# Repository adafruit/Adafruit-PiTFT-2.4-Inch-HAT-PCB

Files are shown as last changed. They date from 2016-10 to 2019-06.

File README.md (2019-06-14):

## Adafruit PiTFT 2.4 Inch HAT PCB

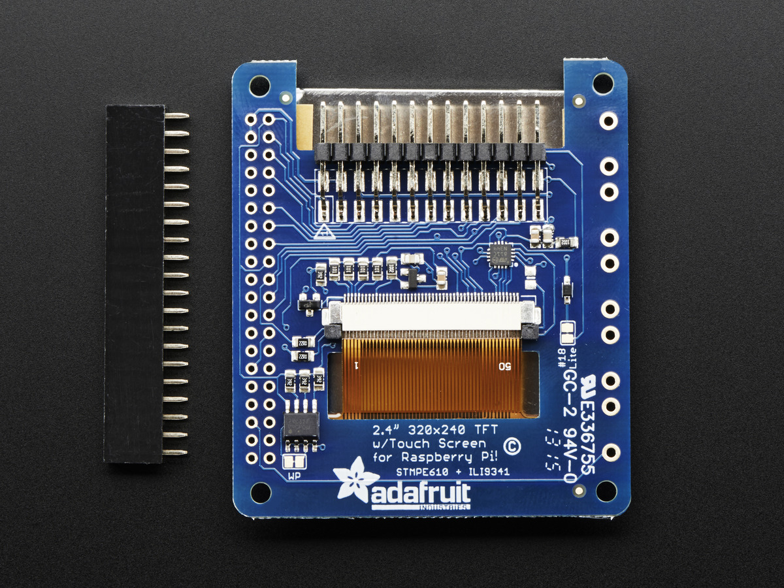
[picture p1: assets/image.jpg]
<a href="http://www.adafruit.com/products/2455"><br/>
Click here to purchase one from the Adafruit shop</a>

PCB files for the Adafruit PiTFT 2.4 Inch HAT. Format is EagleCAD schematic and board layout
* https://www.adafruit.com/product/2455

### DESCRIPTION
Is this not the cutest little display for the Raspberry Pi? It features a 2.4" display with 320x240 16-bit color pixels and a resistive touch overlay. The HAT uses the high speed SPI interface on the Pi and can use the mini display as a console, X window port, displaying images or video etc. Best of all it plugs right in on top!

It's designed to fit nicely onto the Pi Model Zero, A+, B+, Pi 2, Pi 3 - any Pi with a 2x20 connector.

This design uses the hardware SPI pins (SCK, MOSI, MISO, CE0, CE1) as well as GPIO #25 and #24. All other GPIO are unused. Since we had a tiny bit of space, there's 5 spots for optional slim tactile switches wired to five GPIOs, that you can use if you want to make a basic user interface. For example, you can use one as a power on/off button.

We have a right-angle 26-pin connector off to the side. You can connect a classic 26-pin Raspberry Pi GPIO cable in order to access the rest of the GPIO through a Cobbler, etc.

To make it super easy for use: we've created a custom kernel package based of off Notro's awesome framebuffer work, so you can install it over your existing Raspbian (or derivative) images in just a few commands.

Each order ships with an assembled HAT with 2.4" TFT display with resistive touchscreen and a 2x20 female socket header. Some light soldering is required to attach the header but it is easy work for anyone with a soldering iron & solder.Alternatively, you can use a stacking type header instead if you'd like to plug a 2x20 GPIO cable on top

Raspberry Pi, Pi enclosure, 26-pin GPIO cable, tactile switches are not included!

### License

Adafruit invests time and resources providing this open source design, please support Adafruit and open-source hardware by purchasing products from [Adafruit.com](https://www.adafruit.com)!

Creative Commons Attribution, Share-Alike license, check license.txt for more information All text above must be included in any redistribution - 
See license.txt for more information.

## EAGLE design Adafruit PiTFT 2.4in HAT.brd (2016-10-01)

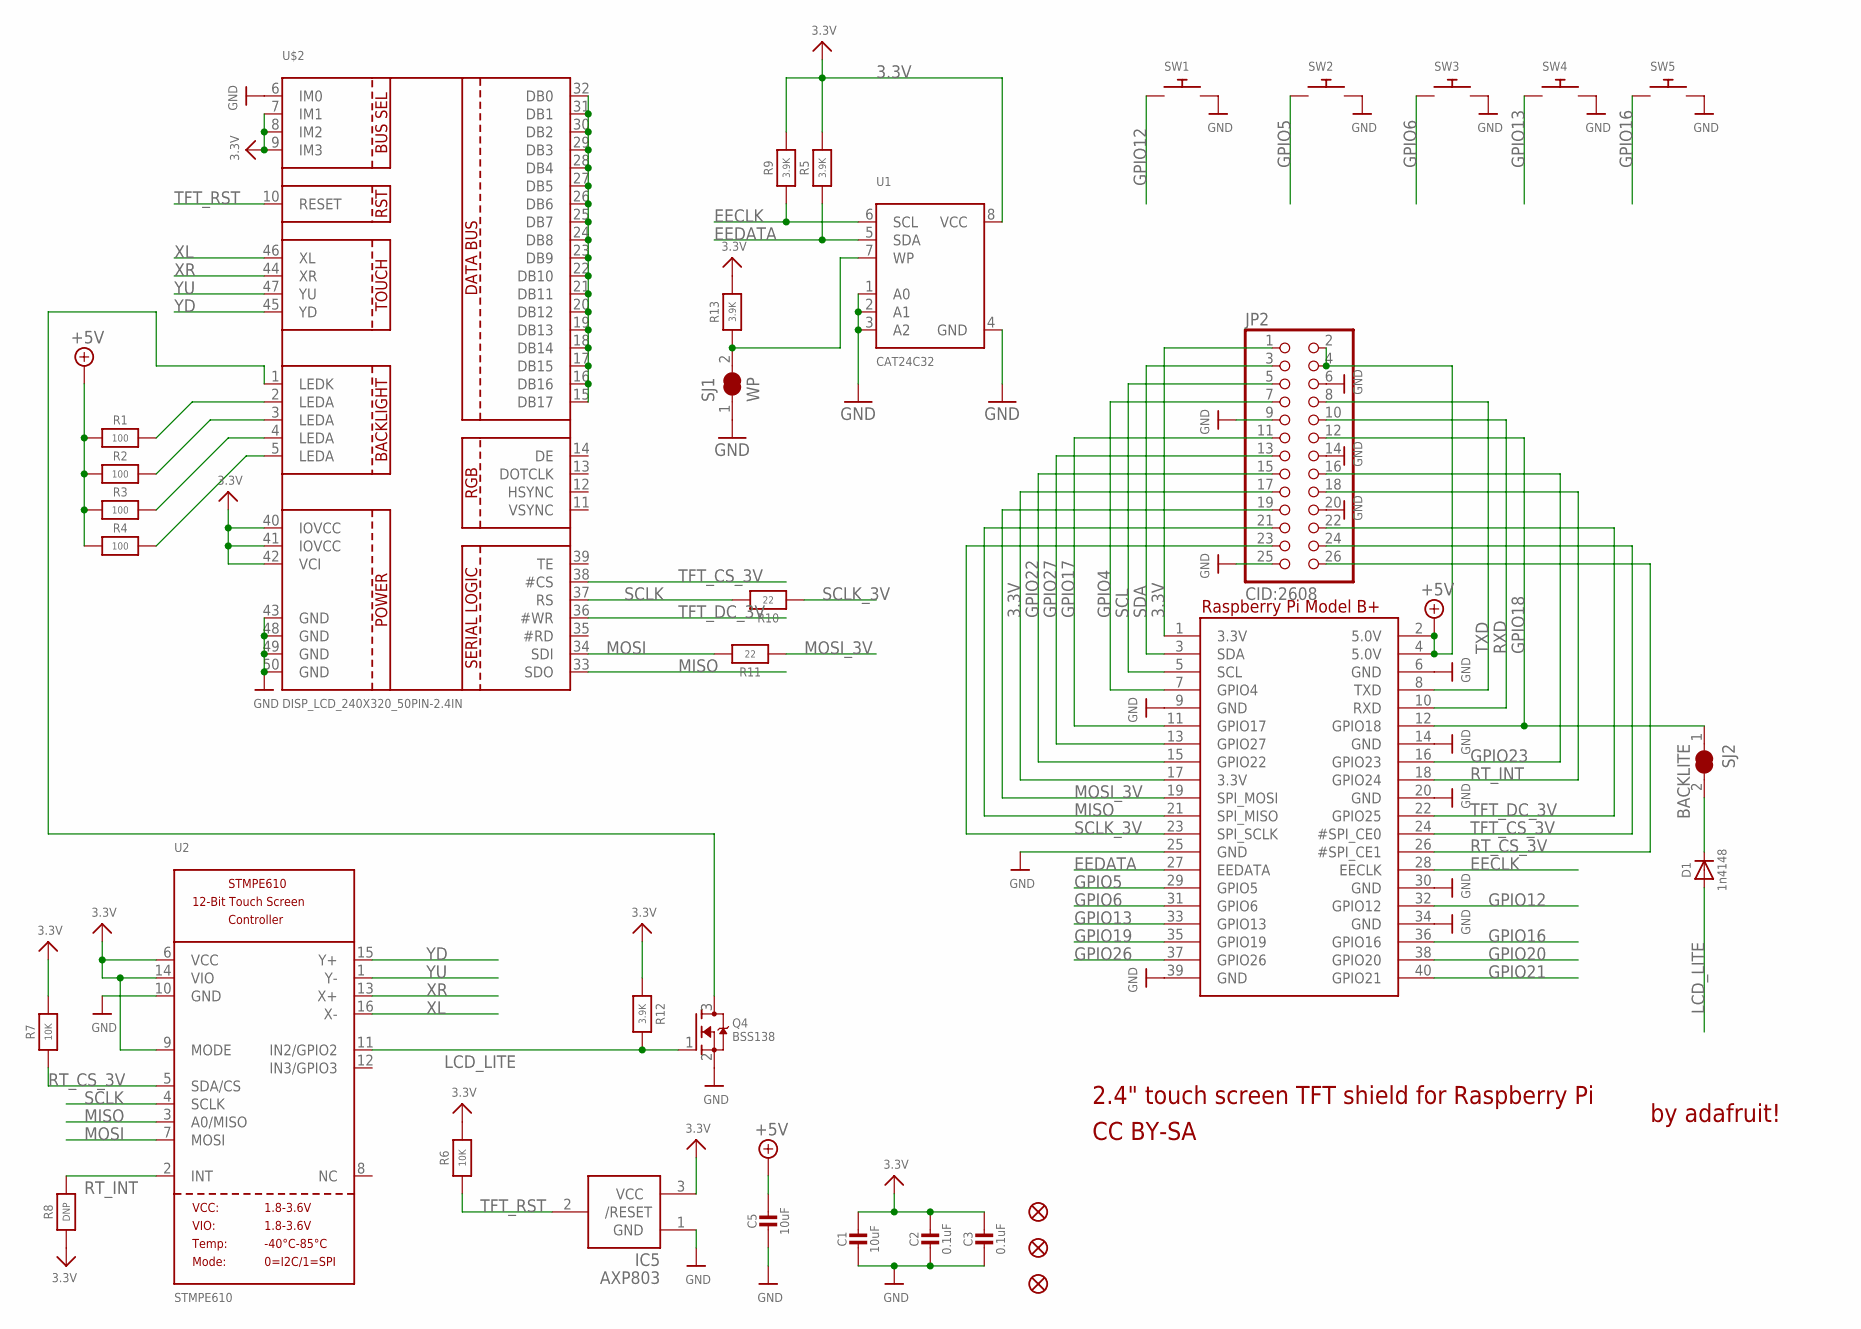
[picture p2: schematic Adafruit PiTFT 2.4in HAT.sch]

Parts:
C1, C5: 10uF; 0805-NO
C2, C3: 0.1uF; 0805-NO
D1: 1n4148; SOD-323
IC5: AXP803; SOT23
JP2: CID:2608; 2X13_SMT_MALE
Q4: BSS138; SOT23-WIDE
R1, R2, R3, R4: 100; 0805-NO
R5, R9, R12, R13: 3.9K; 0805-NO
R6, R7: 10K; 0805-NO
R8: DNP; 0805-NO
R10, R11: 22; 0805-NO
RPI1: RASPBERRYPI_BPLUS_HATNOSLOTS; PI_HAT_NOSLOTS
SJ1: WP; SOLDERJUMPER_CLOSEDWIRE
SJ2: BACKLITE; SOLDERJUMPER_CLOSEDWIRE
SW1, SW2, SW3, SW4, SW5: SWITCH_PUSHBUTTONEVQ-PE; TACT_PANA-EVQ
U1: CAT24C32; SOIC8_150MIL
U2: STMPE610; QFN16_3MM
U$2: DISP_LCD_240X320_50PIN-2.4IN; TFT_2.4IN_240X320_50PIN
U$10, U$11, U$18: FIDUCIAL""; FIDUCIAL_1MM

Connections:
3.3V: C1.1, C2.1, C3.1, IC5.3 (VCC), JP2.1, JP2.17, R5.2, R6.2, R7.2, R8.1, R9.2, R12.1, R13.2, RPI1.1 (3.3V), RPI1.17 (3.3V), U1.8 (VCC), U2.6 (VCC), U2.9 (MODE), U2.14 (VIO), U$2.7 (IM1), U$2.8 (IM2), U$2.9 (IM3), U$2.40 (IOVCC), U$2.41 (IOVCC), U$2.42 (VCI)
+5V: C5.1, JP2.2, JP2.4, R1.1, R2.1, R3.1, R4.1, RPI1.2 (5.0V), RPI1.4 (5.0V)
EECLK: R9.1, RPI1.28 (EECLK), U1.6 (SCL)
EEDATA: R5.1, RPI1.27 (EEDATA), U1.5 (SDA)
GND: C1.2, C2.2, C3.2, C5.2, IC5.1 (GND), JP2.6, JP2.9, JP2.14, JP2.20, JP2.25, Q4.2 (S), RPI1.6 (GND), RPI1.9 (GND), RPI1.14 (GND), RPI1.20 (GND), RPI1.25 (GND), RPI1.30 (GND), RPI1.34 (GND), RPI1.39 (GND), SJ1.1, SW1.P$2, SW2.P$2, SW3.P$2, SW4.P$2, SW5.P$2, U1.1 (A0), U1.2 (A1), U1.3 (A2), U1.4 (GND), U2.10 (GND), U$2.6 (IM0), U$2.43 (GND), U$2.48 (GND), U$2.49 (GND), U$2.50 (GND)
GPIO4: JP2.7, RPI1.7 (GPIO4)
GPIO5: RPI1.29 (GPIO5), SW2.P$1
GPIO6: RPI1.31 (GPIO6), SW3.P$1
GPIO12: RPI1.32 (GPIO12), SW1.P$1
GPIO13: RPI1.33 (GPIO13), SW4.P$1
GPIO16: RPI1.36 (GPIO16), SW5.P$1
GPIO17: JP2.11, RPI1.11 (GPIO17)
GPIO18: JP2.12, RPI1.12 (GPIO18), SJ2.1
GPIO19: RPI1.35 (GPIO19)
GPIO20: RPI1.38 (GPIO20)
GPIO21: RPI1.40 (GPIO21)
GPIO22: JP2.15, RPI1.15 (GPIO22)
GPIO23: JP2.16, RPI1.16 (GPIO23)
GPIO26: RPI1.37 (GPIO26)
GPIO27: JP2.13, RPI1.13 (GPIO27)
LCD_LITE: D1.A, Q4.1 (G), R12.2, U2.11 (IN2/GPIO2)
MISO: JP2.21, RPI1.21 (SPI_MISO), U2.3 (A0/MISO), U$2.33 (SDO)
MOSI: R11.2, U2.7 (MOSI), U$2.34 (SDI)
MOSI_3V: JP2.19, R11.1, RPI1.19 (SPI_MOSI)
unnamed: R1.2, U$2.2 (LEDA)
unnamed: R2.2, U$2.3 (LEDA)
unnamed: R3.2, U$2.4 (LEDA)
unnamed: Q4.3 (D), U$2.1 (LEDK)
unnamed: D1.C, SJ2.2
unnamed: U$2.15 (DB17), U$2.16 (DB16), U$2.17 (DB15), U$2.18 (DB14), U$2.19 (DB13), U$2.20 (DB12), U$2.21 (DB11), U$2.22 (DB10), U$2.23 (DB9), U$2.24 (DB8), U$2.25 (DB7), U$2.26 (DB6), U$2.27 (DB5), U$2.28 (DB4), U$2.29 (DB3), U$2.30 (DB2), U$2.31 (DB1), U$2.32 (DB0)
unnamed: R4.2, U$2.5 (LEDA)
unnamed: R13.1, SJ1.2, U1.7 (WP)
RT_CS_3V: JP2.26, R7.1, RPI1.26 (#SPI_CE1), U2.5 (SDA/CS)
RT_INT: JP2.18, R8.2, RPI1.18 (GPIO24), U2.2 (INT)
RXD: JP2.10, RPI1.10 (RXD)
SCL: JP2.5, RPI1.5 (SCL)
SCLK: R10.2, U2.4 (SCLK), U$2.37 (RS)
SCLK_3V: JP2.23, R10.1, RPI1.23 (SPI_SCLK)
SDA: JP2.3, RPI1.3 (SDA)
TFT_CS_3V: JP2.24, RPI1.24 (#SPI_CE0), U$2.38 (#CS)
TFT_DC_3V: JP2.22, RPI1.22 (GPIO25), U$2.36 (#WR)
TFT_RST: IC5.2 (/RESET), R6.1, U$2.10 (RESET)
TXD: JP2.8, RPI1.8 (TXD)
XL: U2.16 (X-), U$2.46 (XL)
XR: U2.13 (X+), U$2.44 (XR)
YD: U2.15 (Y+), U$2.45 (YD)
YU: U2.1 (Y-), U$2.47 (YU)

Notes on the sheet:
2.4" touch screen TFT shield for Raspberry Pi
by adafruit!
CC BY-SA

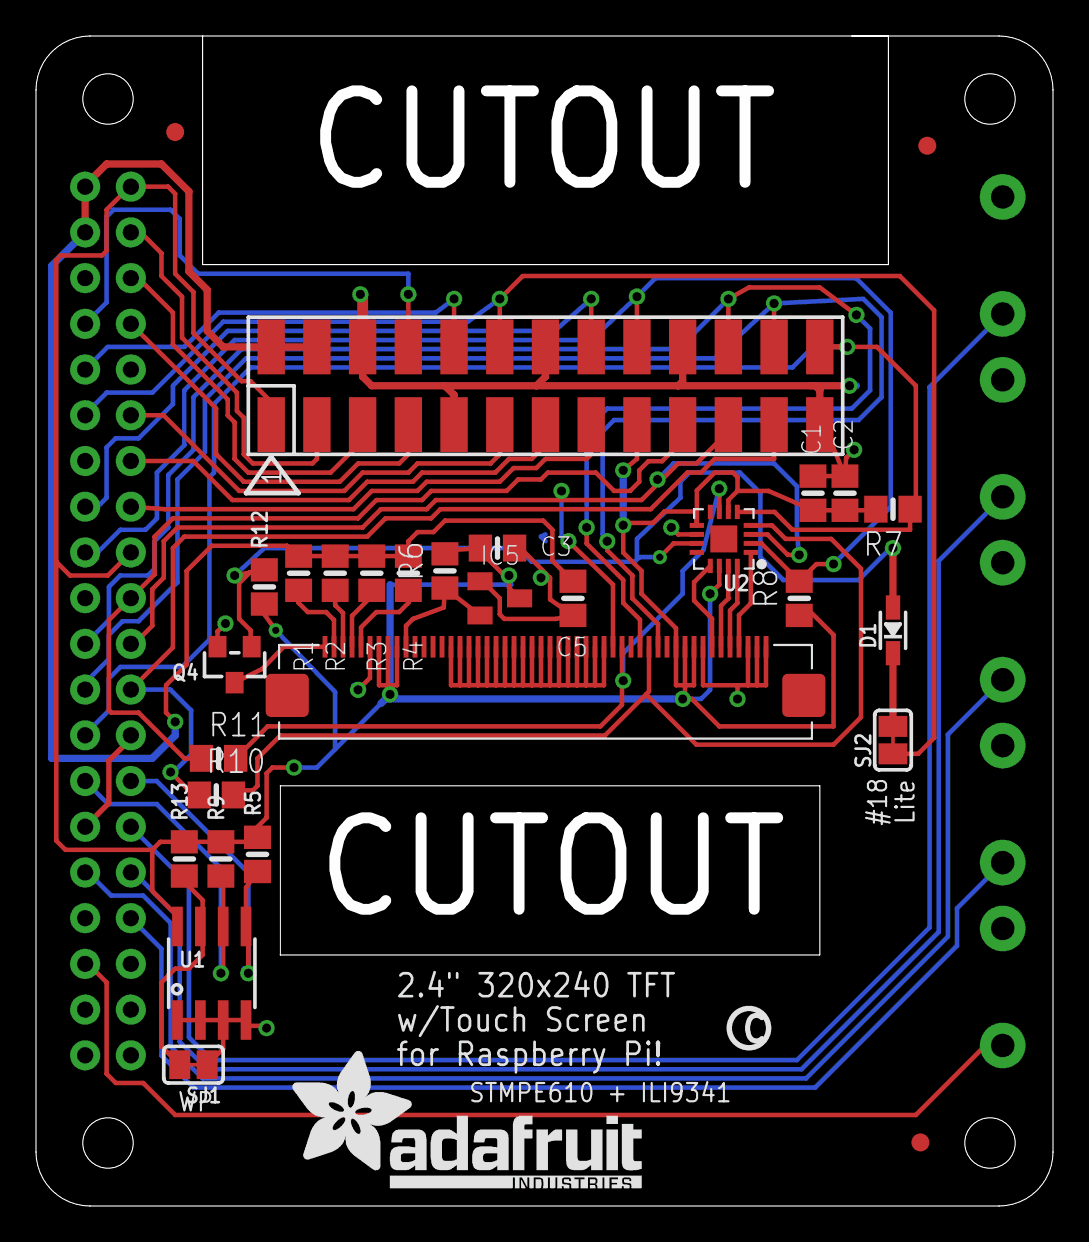
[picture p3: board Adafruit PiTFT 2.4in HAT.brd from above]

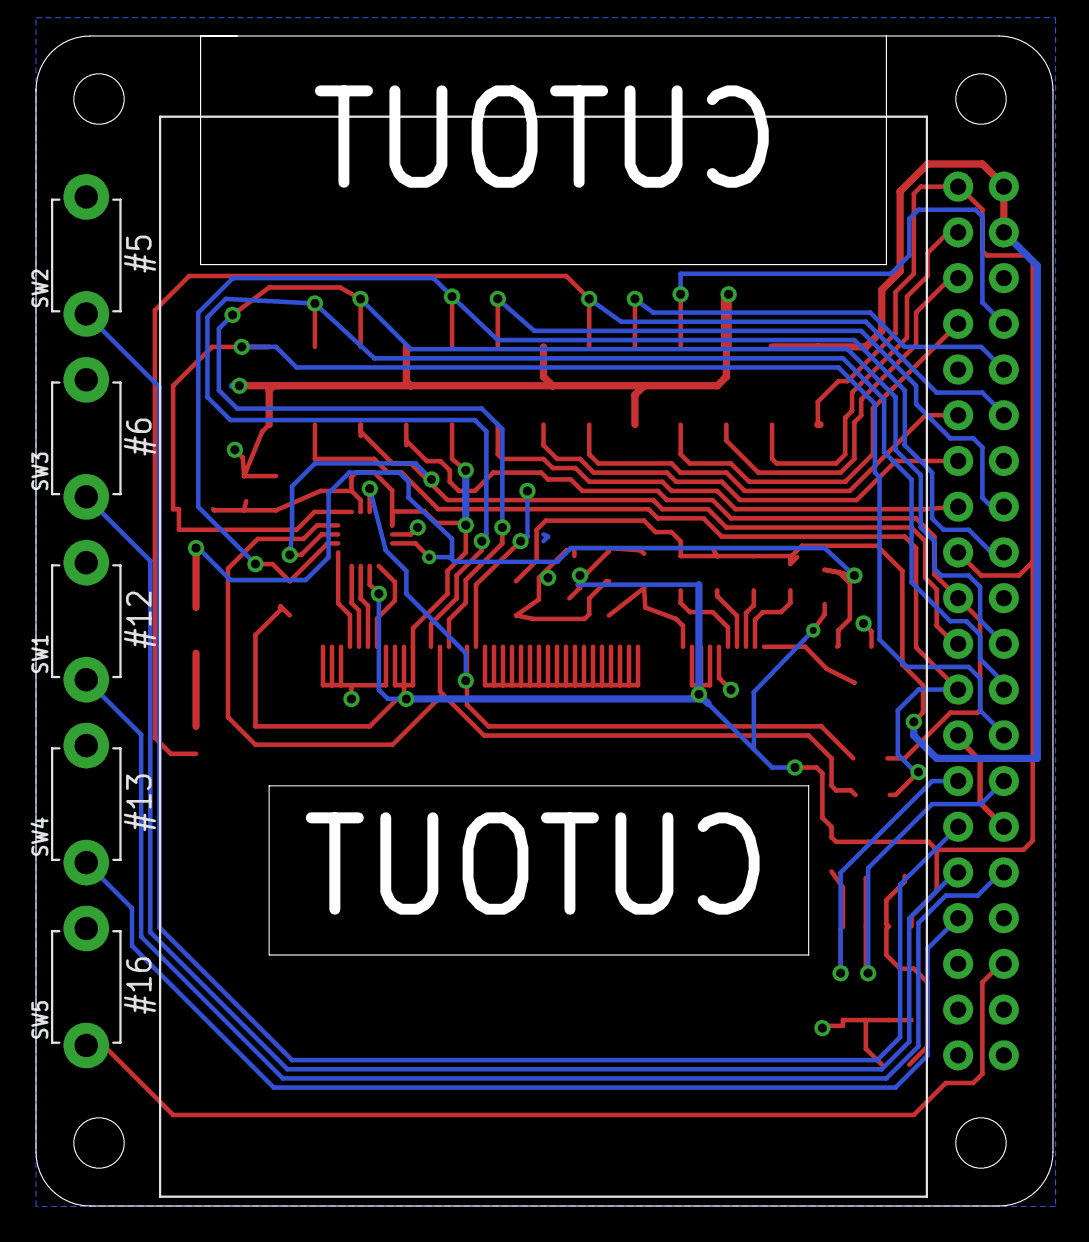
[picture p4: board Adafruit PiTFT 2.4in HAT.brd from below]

Board: 2 copper layers, 56.5 x 65.0 mm, 37 parts (7 on the bottom side), 43 nets.

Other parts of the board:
U$9: PCBFEAT-REV-056
U$23: ADAFRUIT_TEXT_20MM
